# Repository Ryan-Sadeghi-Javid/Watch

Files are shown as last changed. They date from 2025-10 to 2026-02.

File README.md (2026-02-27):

# LCD display
1.69" LCD display PCB with on-board accelerometer, buzzer, and debugging interface

## Feature Summary
- **Rechargeable 3.7V LiPo battery cell:** 320 mAh battery pack, charged via USB-C (fits under PCB)
  - Reverse-polarity protection (ideal diode) + regulation
- **Accelerometer:** 3-axis accelerometer via **I2C** for motion detection
- **Buzzer:** magnetic buzzer via **PWM** (frequency control for tone/volume), **flyback diode** for inductive kickback protection
- **Display:** 1.69" LCD via **4-wire SPI**
- **Debug:** SWD header (3V3, SWDIO, SWCLK, NRST, GND)

---

## System Overview (Block Diagram)
High-level architecture showing power path + STM32 peripherals (SPI display, I2C accel, PWM buzzer, SWD debug).

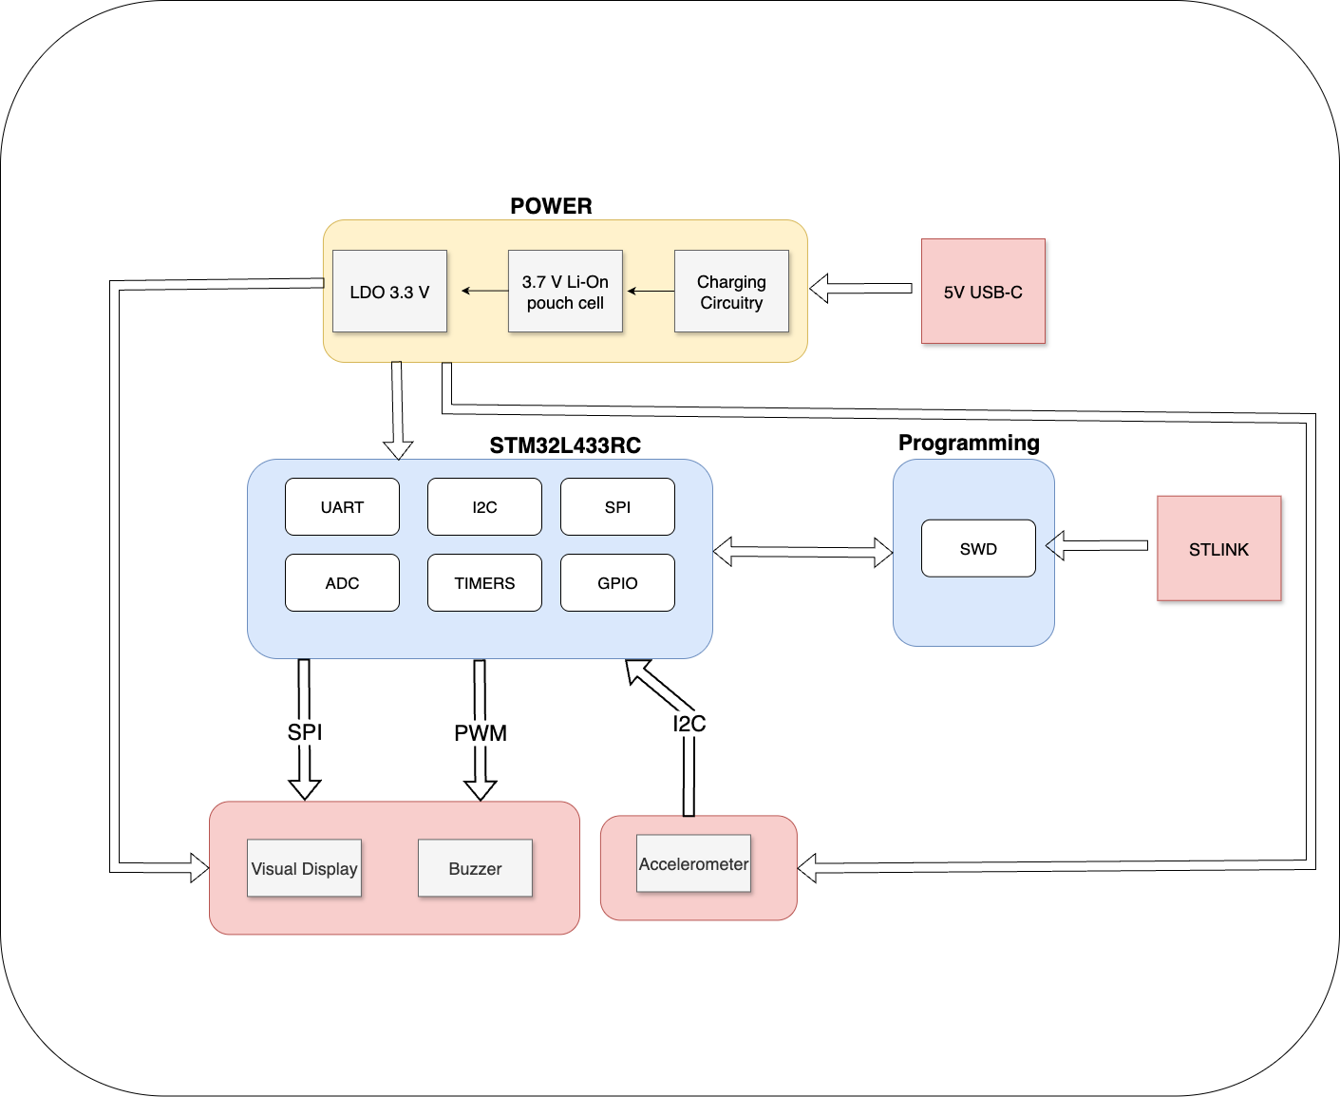
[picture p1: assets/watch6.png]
System block diagram


---

## Mechanical / Assembly View
Stacked assembly render showing the compact form factor and how the display sits above the PCB.

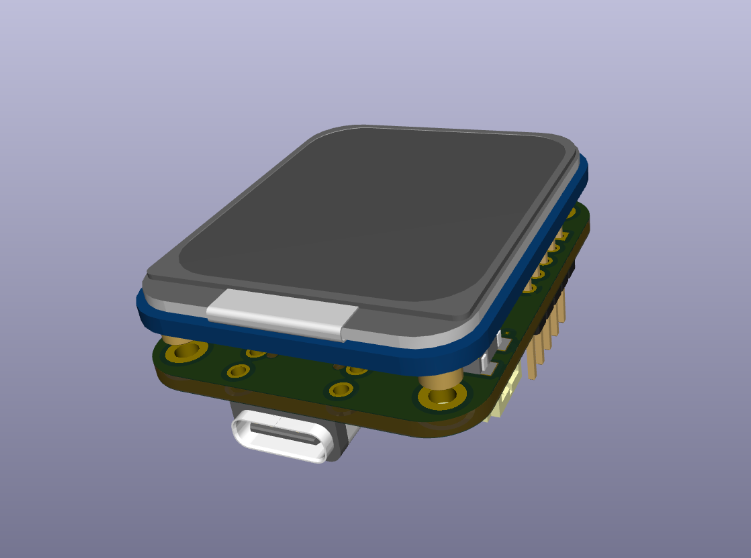
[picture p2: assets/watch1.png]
Assembly / stacked render


---

## 3D PCB Renders

### Component Side (MCU + power + sensor/buzzer circuitry)
3D render of the main board side with the STM32 and supporting circuitry.

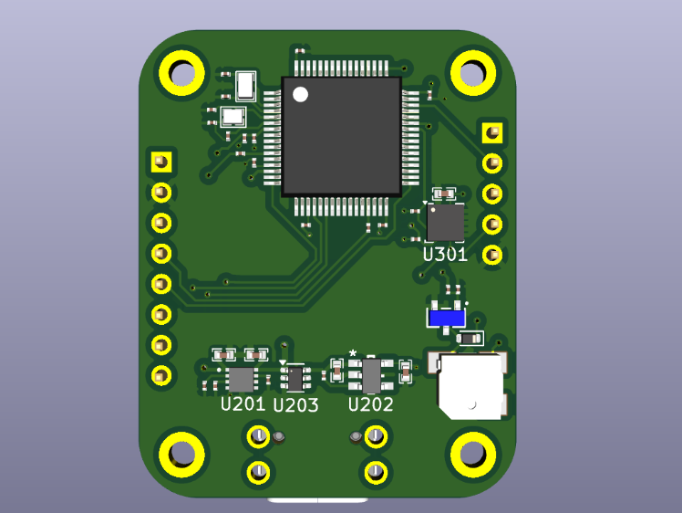
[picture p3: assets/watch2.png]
3D render - component side


### Connector Side (USB-C + SWD header access)
3D render showing USB-C placement and the SWD/debug header labeling.

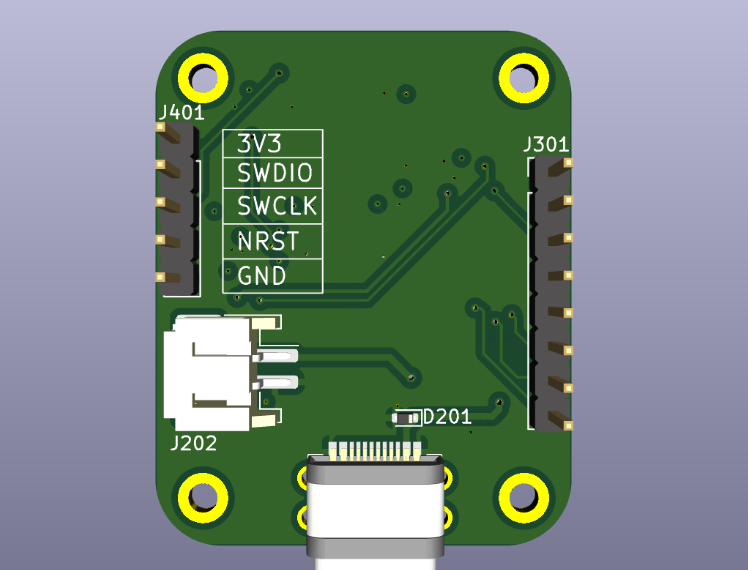
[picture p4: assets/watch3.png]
3D render - connector side


---

## PCB Layout (KiCad)

### Overall routed layout (all layers visible)
Screenshot of the routed board in KiCad (routing + pours + placement).

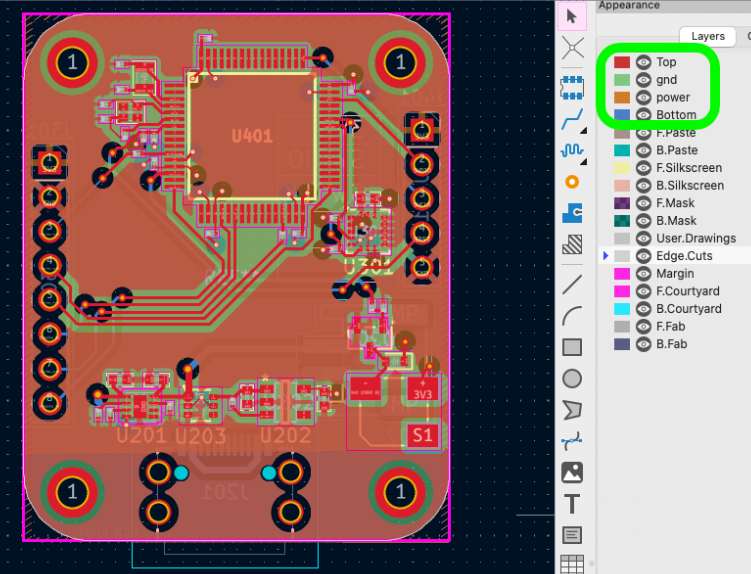
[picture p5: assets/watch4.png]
KiCad routed layout


### Top layer (routing + pours) + board dimensions
Top copper view with pours and routing, including overall board dimensions.

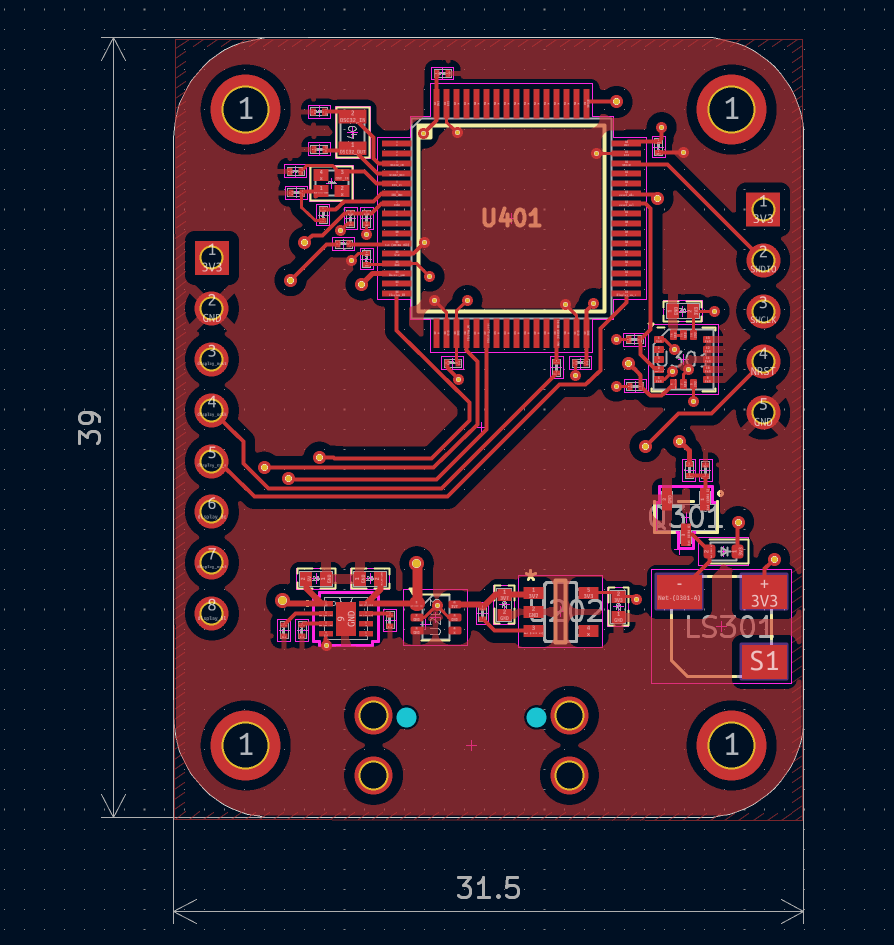
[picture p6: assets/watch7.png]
Top layer + dimensions


### Bottom layer (routing + pours)
Bottom copper view showing routing/pours on the underside.

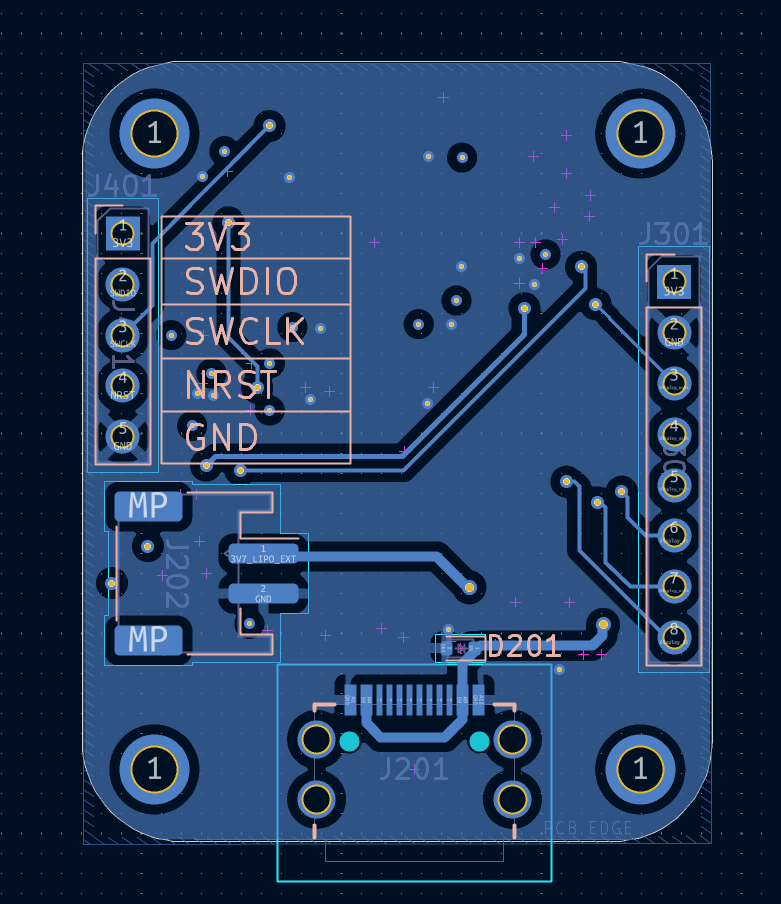
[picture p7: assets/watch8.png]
Bottom layer


### Layer legend used in screenshots
Reference legend for the layer colors used in the KiCad screenshots.

Layer legend

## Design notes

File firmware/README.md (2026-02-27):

# Watch Firmware

Firmware for Watch-style Wearable PCB:
- STM32 (HAL)
- I2C accelerometer (LIS3DH-style driver; adaptable)
- SPI LCD (ST7789 driver; adaptable)
- PWM buzzer
- SWD debugging

## Build steps
1) Create STM32CubeIDE project with CubeMX (.ioc)
2) Enable I2C, SPI, PWM timer, GPIO pins listed in platform/board.h
3) Drop these sources into Core/Src and headers into Core/Inc (or keep folder structure and update include paths)
4) Compile + flash via ST-Link (SWD)

## Bring-up order
1) Blink LED
2) I2C WHO_AM_I read
3) LCD init + fill screen
4) PWM buzzer tone test
5) Integrate main app loop

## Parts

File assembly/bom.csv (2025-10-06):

Reference | Qty | MFG | MFG P/N
C201,C202,C203,C204,C301 | 5 | Murata Electronics | GRM155Z71A105KE01J
C401,C402 | 2 | Murata Electronics | GRM0335C1H120FA01D
C403,C404 | 2 | Murata Electronics | GRM0335C1H150FA01D
C405,C406,C407,C408,C409,C410 | 6 | Murata Electronics | GRM033Z71A104KE14D
D201 | 1 | onsemi | ESD5Z6.0T1G
D301 | 1 | onsemi | RB520S30T1G
J201 | 1 | Global Connector Technology | USB4730-GF-A-KIT
J202 | 1 | JST | S2B-PH-SM4-TB
J301 | 1 | Wurth Elektronik | 61300811121
J401 | 1 | Wurth Elektronik | 61300511121
LS301 | 1 | Pui Audio | SMT-0540-T-9-R
N301 | 1 | seeed studio | 1_69inch-lcd-module
Q301 | 1 | Toshiba Semiconductor and Storage | T2N7002AK,LM
R201 | 1 | YAGEO | RC0201FR-07953RL
R202,R204,R301,R302,R304,R404 | 6 | YAGEO | RC0201FR-0710KL
R203 | 1 | YAGEO | RC0201FR-0761K9L
R303 | 1 | YAGEO | RC0201FR-071KL
R401,R403 | 2 | YAGEO | RC0201FR-0722RL
R402 | 1 | YAGEO | RC0201FR-071K1L
U201 | 1 | Texas Instruments | BQ25176MDSGR
U202 | 1 | Texas Instruments | TLV75533PDBVR
U203 | 1 | Texas Instruments | LM66100DCKR
U301 | 1 | STMicroelectronics | LIS3DH
U401 | 1 | STMicroelectronics | STM32L433RCT6
Y401 | 1 | NKG | 01-CR3-06-32k768
Y402 | 1 | NKG | S1M

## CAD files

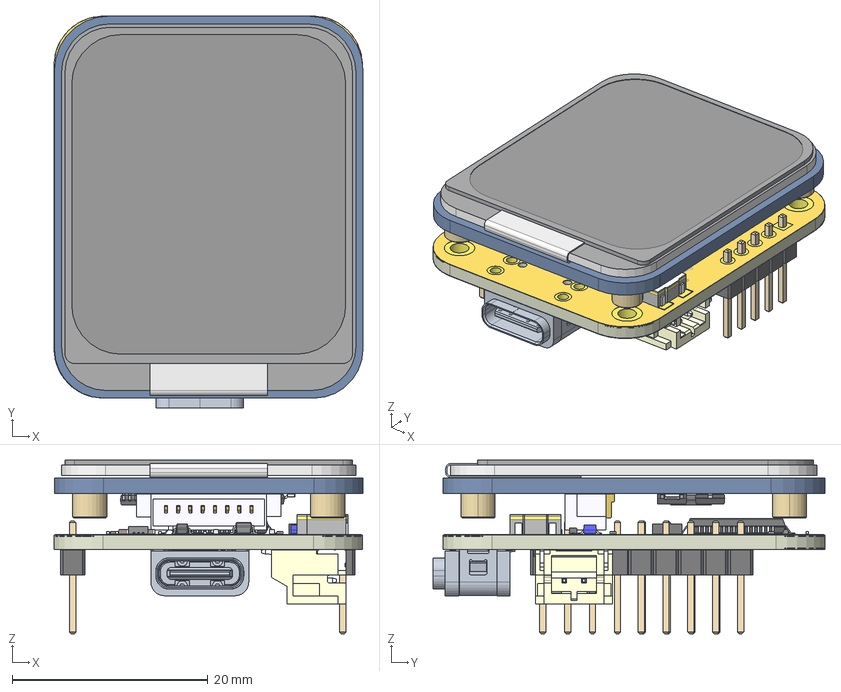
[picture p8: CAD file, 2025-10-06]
pcb.step
31.6 x 40.0 x 17.7 mm
0201_0603Metric x 22
LGA-16_3x3mm_P0.5mm_LayoutBorder3x5y
TOS_T2N7002AK
S1M_1612
0402_1005Metric x 5
BODY-SOT
LEAD-SOT x 5
LEAD-DUMMY
1_69INCH-240X280-LCD
1_69INCH_LCD_MODULE-PCBA
STUDS-M2XH2_5 x 4
STM32L433RCT6
BODY-SON
PIN1-ID
D_SOD-523 x 2
SOT-363_SC-70-6
PUI_SMT-0540-T-9-R
NKG_CR3_2012
simon 1.39.1
PinHeader_1x08_P2.54mm_Vertical
PinHeader_1x05_P2.54mm_Vertical
JST_S2B-PH-SM4-TB
simon_copper
simon_silkscreen
simon_soldermask
simon_PCB

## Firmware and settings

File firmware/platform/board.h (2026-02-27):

#pragma once
#include "stm32f4xx_hal.h"

extern I2C_HandleTypeDef hi2c1;
extern SPI_HandleTypeDef hspi1;
extern TIM_HandleTypeDef htim3;

// ------------ LCD GPIO ------------
#define LCD_CS_GPIO_Port   GPIOA
#define LCD_CS_Pin         GPIO_PIN_4

#define LCD_DC_GPIO_Port   GPIOA
#define LCD_DC_Pin         GPIO_PIN_6

#define LCD_RST_GPIO_Port  GPIOA
#define LCD_RST_Pin        GPIO_PIN_7

#define LCD_BL_GPIO_Port   GPIOB
#define LCD_BL_Pin         GPIO_PIN_0

// ------------ Optional LED ------------
#define LED_GPIO_Port      GPIOC
#define LED_Pin            GPIO_PIN_13

// ------------ Buzzer PWM ------------
#define BUZZER_TIM         (&htim3)
#define BUZZER_TIM_CH      TIM_CHANNEL_1

// Board init hooks
void Board_Init(void);
void Board_DelayMs(uint32_t ms);
uint32_t Board_Millis(void);

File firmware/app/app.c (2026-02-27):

#include "app.h"
#include "platform/board.h"
#include "platform/log.h"
#include "drivers/accel/lis3dh.h"
#include "drivers/display/st7789.h"
#include "drivers/display/gfx.h"
#include "drivers/buzzer/buzzer.h"

static Lis3dh accel;
static ST7789 lcd;
static Buzzer buzzer;

static uint32_t last_led = 0;
static uint32_t last_ui  = 0;

// --------- lightweight int -> string helpers (no snprintf/printf) ---------
static char* write_u16(char* p, uint16_t v) {
  char tmp[5];
  int n = 0;

  if (v == 0) {
    *p++ = '0';
    return p;
  }

  while (v > 0 && n < (int)sizeof(tmp)) {
    tmp[n++] = (char)('0' + (v % 10));
    v /= 10;
  }
  while (n--) *p++ = tmp[n];
  return p;
}

static char* write_i16(char* p, int16_t v) {
  if (v < 0) {
    *p++ = '-';
    uint16_t mag = (uint16_t)(-(int32_t)v);
    return write_u16(p, mag);
  }
  return write_u16(p, (uint16_t)v);
}

static void build_xyz_line(char* out, size_t out_sz, int16_t x, int16_t y, int16_t z) {
  if (out_sz == 0) return;

  char* p = out;
  char* end = out + out_sz - 1;

  if (p < end) *p++ = 'X';
  if (p < end) *p++ = ':';
  if (p < end) p = write_i16(p, x);

  if (p < end) *p++ = ' ';
  if (p < end) *p++ = 'Y';
  if (p < end) *p++ = ':';
  if (p < end) p = write_i16(p, y);

  if (p < end) *p++ = ' ';
  if (p < end) *p++ = 'Z';
  if (p < end) *p++ = ':';
  if (p < end) p = write_i16(p, z);

  for (int i = 0; i < 6 && p < end; i++) *p++ = ' '; // clear old chars

  *p = '\0';
}

void App_Init(void) {
  // ----- Accelerometer -----
  lis3dh_init_t ainit = {
    .i2c = &hi2c1,
    .addr_7bit = 0x18,
  };
  if (!lis3dh_init(&accel, &ainit)) {
    LOGE("Accel init failed");
  } else {
    LOGI("Accel ok");
  }

  // ----- LCD -----
  st7789_init_t linit = {
    .spi = &hspi1,
    .cs_port = LCD_CS_GPIO_Port, .cs_pin = LCD_CS_Pin,
    .dc_port = LCD_DC_GPIO_Port, .dc_pin = LCD_DC_Pin,
    .rst_port = LCD_RST_GPIO_Port, .rst_pin = LCD_RST_Pin,
    .width = 240,
    .height = 280,
    .x_offset = 0,
    .y_offset = 20,
  };

  st7789_init(&lcd, &linit);
  st7789_fill(&lcd, 0x0000);

  // ----- Buzzer -----
  buzzer_init(&buzzer, BUZZER_TIM, BUZZER_TIM_CH);
  buzzer_tone(&buzzer, 1200, 20, 120);

  gfx_draw_string(&lcd, 10, 10, "WATCH BOOT", 0xFFFF, 0x0000);
}

void App_Tick(void) {
  uint32_t now = Board_Millis();

  // 2Hz BLINKING
  if (now - last_led > 250) {
    last_led = now;
    HAL_GPIO_TogglePin(LED_GPIO_Port, LED_Pin);
  }

  // 10Hz UI updates
  if (now - last_ui > 100) {
    last_ui = now;

    int16_t x=0,y=0,z=0;
    if (lis3dh_read_xyz(&accel, &x, &y, &z)) {
      char buf[48];
        build_xyz_line(buf, sizeof(buf), x, y, z);
        gfx_draw_string(&lcd, 10, 40, buf, 0x07E0, 0x0000);
    }
  }
}
